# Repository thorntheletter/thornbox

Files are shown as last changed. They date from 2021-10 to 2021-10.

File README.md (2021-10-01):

# thornbox
Custom stickless controller compatible (probably) with most Brooks boards

This is my first time doing PCB design, CAD, and 3D printing so it is probably a bit rough.

## Current Issues:
* The DIP Switch description for tournament lockout is reversed.
* There is not enough room in the top of the case for player LEDs.
* Snackbox Micro buttons end up awkwardly high.
* 3D Printed buttons can be fragile and break easily.
* DP/LS/RS switches do not work. (I believe this to be a problem on the PCB manufacturers end.)
* The screws needing to go from bottom to top through PCB are tricky to get in right.
* I did not have the filament to iterate the tolerances more than once after fixing underextrusion.
* The files to generate pcb graphics footprints are missing (I may also need the hotswap socket / USB-C port footprints)
* The USB-C port is a pain to solder by hand.

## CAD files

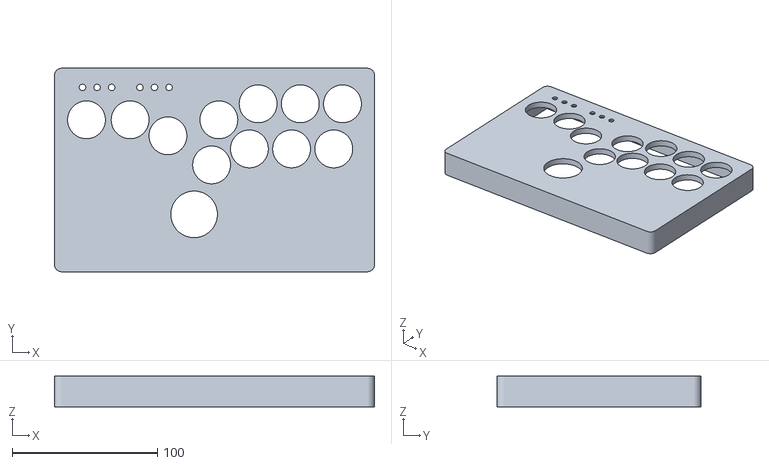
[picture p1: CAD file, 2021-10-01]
production/stl/top.stl
220.0 x 140.0 x 21.0

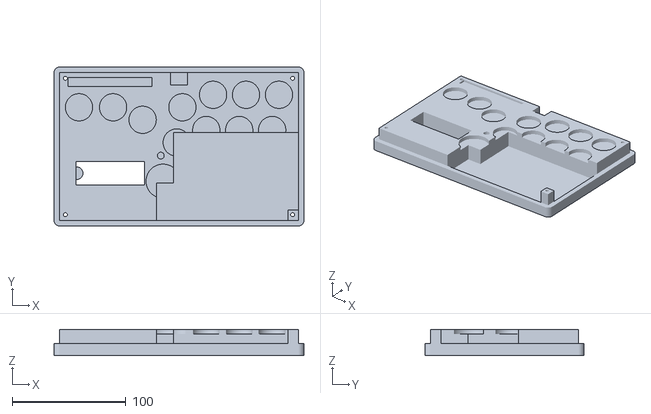
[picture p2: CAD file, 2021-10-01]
production/stl/bottom.stl
220.0 x 140.0 x 23.0

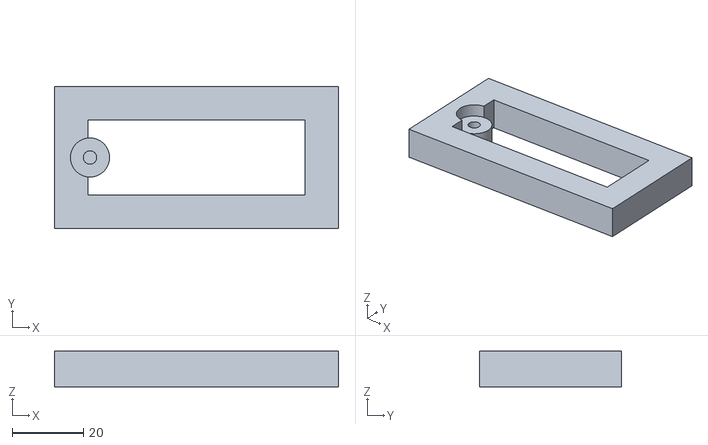
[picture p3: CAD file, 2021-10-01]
production/stl/diphatch.stl
80.0 x 40.0 x 10.0

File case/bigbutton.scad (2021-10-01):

$fa = .1;
$fs = .1;
module bigbutton(){
    union(){
        difference(){
            translate ([0,0,4]) minkowski(){
                        cylinder(2.5,r=15-4);
                        difference(){
                            sphere(r=4);
                            translate([0,0,50]) cube(100, center=true);
                       
                }
            }
            translate([0,0,1.5]) cylinder(9, r=15-1.5);
        }
        translate([0,2.85,1+2-.5]) cube([2.5,.9,5], center = true);
        translate([0,-2.85,1+2-.5]) cube([2.5,.9,5], center=true);
    }
}
bigbutton();

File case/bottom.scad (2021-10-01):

$fa = .1;
$fs = .1;
use <diphatch.scad>
layout = [[17,30.5],[47,30.5],[73,41.5],[91,95.5],
          [108,30.5],[135,19.5],[164,19.5],[193,19.5],
          [103,61.5],[129,50.5],[158,50.5],[187,50.5]];
upbutton = [91,95.5];
screws = [[89,57],[205,55],[117,5],[117,42],[205,42],[105,5]];
cornerscrews = [[5,125],[205,125],[5,5],[205,5]];
br = 10.6; //bottom rim
bh = 3; //how much space on bottom
eh = 20; //how much space to pcb(s)
hh = 100; //arbitrarily large for holes
sh = 2; //tht back side solder

module bottom(){
    union(){
   difference(){
        union(){
            difference(){        
                union(){
                    difference(){
                        minkowski(){
                                cube([210,130,br-1]);
                                cylinder(1,r=5);
                            
                        }
                        cube([210,130,eh+bh]);

                    }
                    cube([210,130,eh+bh]);
                }
                for(i = layout){
                    translate([i[0],130-i[1],bh+eh-4]) cylinder(hh, r=12);
                }
                translate([upbutton[0],130-upbutton[1],bh+eh-4]) cylinder(hh, r=15);
//                translate([14.25-7,130-8.25-4,bh+eh-sh]) cube([74,8,hh]);
                translate([14.25-7,130-8.25-4,bh+eh-sh]) cube([74,8,hh]);
//                translate([97.5,130-11,bh+eh-8]) cube([15,20,hh]);
                translate([97.5,130-11,bh+eh-8]) cube([15,20,hh]);
                translate([100,0,bh]) cube([110,130-52.5,hh]);
                translate([85,0,bh]) cube([210-85,130-97.,hh]);
                translate([15-.5,31.5-.5,-hh/2]) cube([60,21,hh]);
        translate([5,31.5-10,-hh+10]) cube([80,40,hh]);
            }

            translate([205.5,4.5,(bh+eh)/2]) cube([9,9,bh+eh], center=true);
        }
        for(i=cornerscrews){
            translate([i[0],i[1],-hh/2]) cylinder(hh, r=3.5/2);
            translate([i[0],i[1],-1]) cylinder(5.5, r=3);
        }
        for(i=screws){
            translate([i[0],i[1],eh+bh-3]) cylinder(3.5, r=3);
        }
    }
        translate([(15-10),40+(31.5-10),10]) rotate([180,0,0]) diphatch();
        
    }
}
bottom();

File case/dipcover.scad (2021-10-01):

$fa = .1;
$fs = .1;
difference(){
    union(){
        translate([0,-.25,0]) cube([60,20.5,4]);
        translate([59,17.5-15,0]) cube([5,5,1]);
        translate([59,17.5-5,0]) cube([5,5,1]);
        translate([0,10,0]) cylinder(h=4, r=5);
    }
    translate([0,10,-1]) cylinder(h=6, r=3.5/2);
    translate([0,10,2]) cylinder(h=6, r=3);
}

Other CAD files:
case/diphatch.scad
case/full.scad
case/smallbutton.scad
case/top.scad

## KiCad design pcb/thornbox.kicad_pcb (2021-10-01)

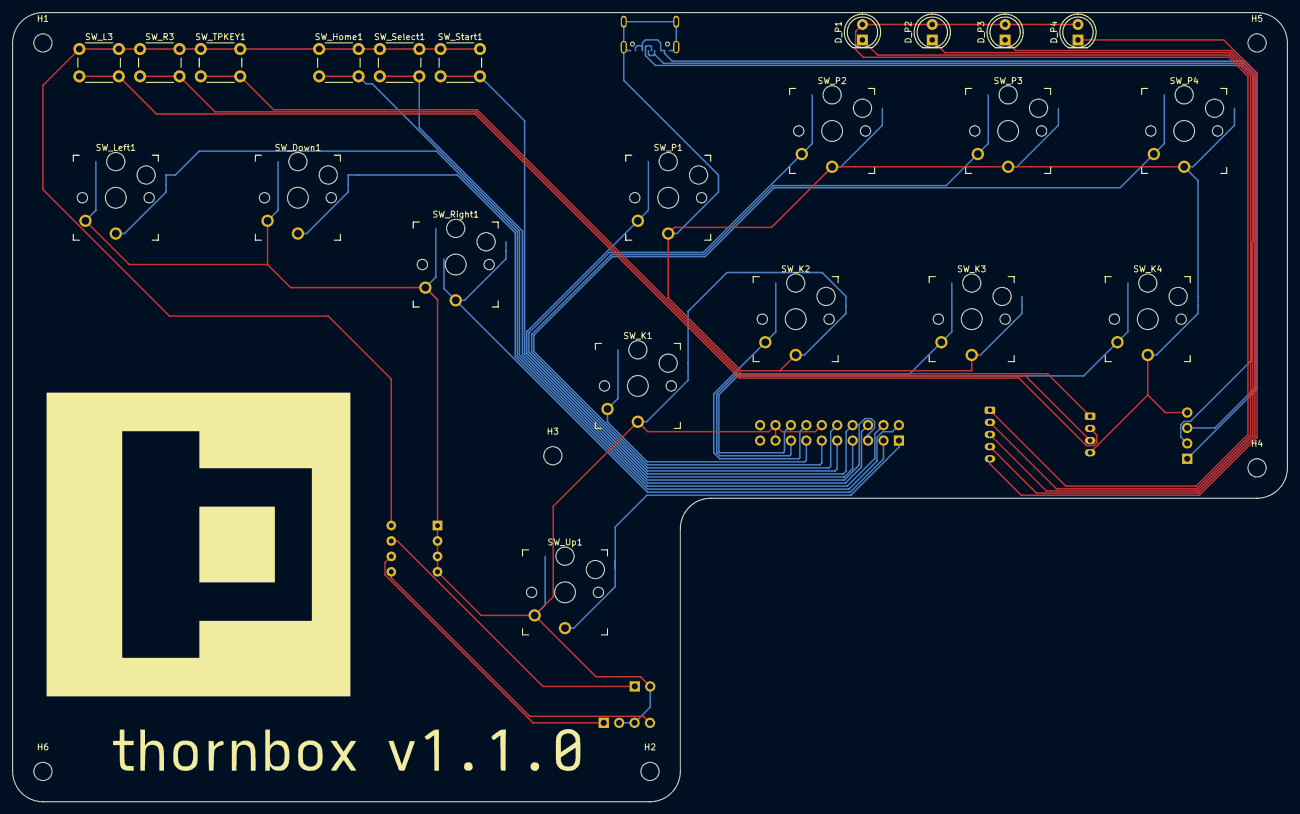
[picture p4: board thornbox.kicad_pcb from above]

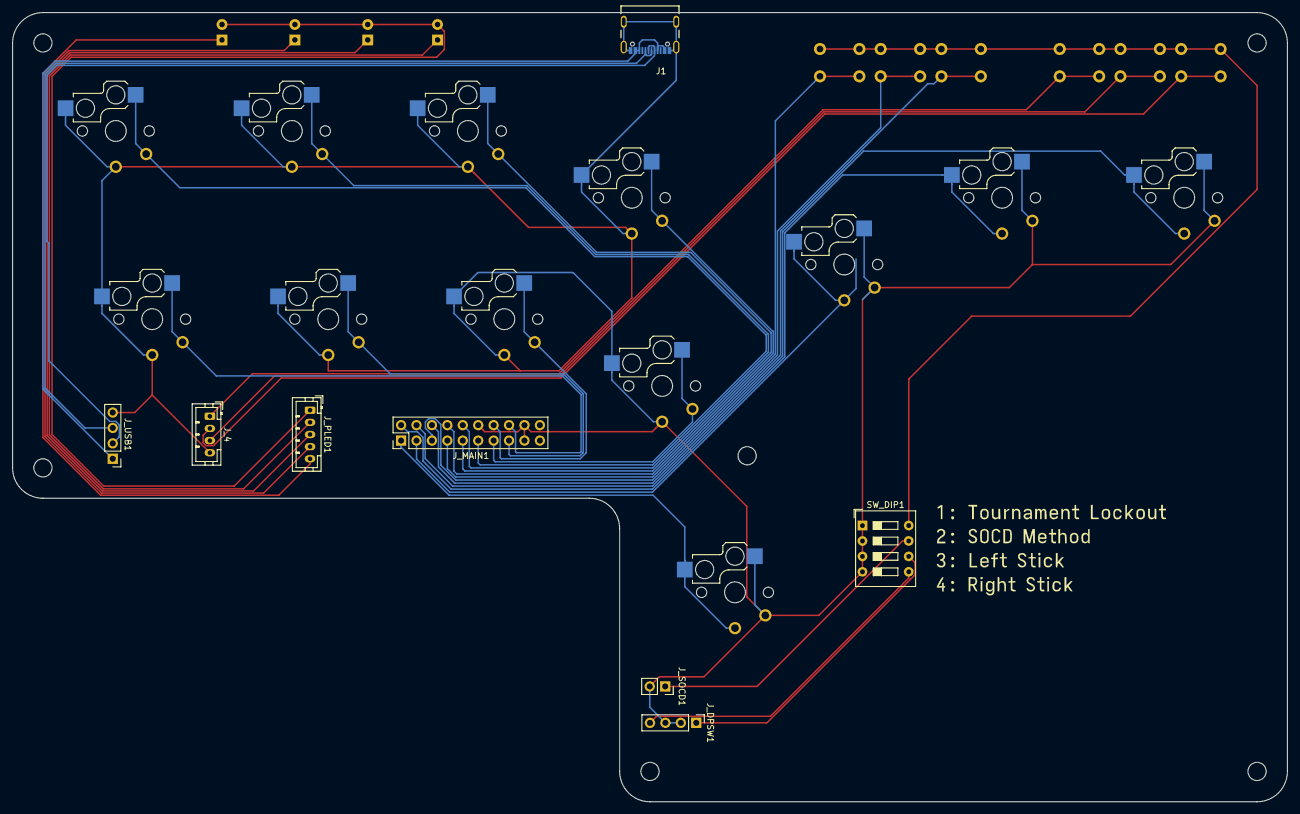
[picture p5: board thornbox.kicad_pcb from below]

Board: 2 copper layers, 210.0 x 130.0 mm, 39 parts (9 on the bottom side), 31 nets.

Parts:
DIPtext1: MountingHole; diplabel
D_P1, D_P2, D_P3, D_P4: LED; LED_D5.0mm
H1, H2, H3, H4, H5, H6: MountingHole; MountingHole_3mm
J1: USB4105-GF-A; GCT_USB4105-GF-A
J_4: Conn_01x04_Male; JST_PH_B4B-PH-K_1x04_P2.00mm_Vertical
J_DPSW1: Conn_01x04; PinHeader_1x04_P2.54mm_Vertical
J_MAIN1: Conn_02x20_Odd_Even; PinHeader_2x10_P2.54mm_Vertical
J_PLED1: Conn_01x05; JST_PH_B5B-PH-K_1x05_P2.00mm_Vertical
J_SOCD1: Conn_01x02; PinSocket_1x02_P2.54mm_Vertical
J_USB1: Conn_01x04_Male; PinHeader_1x04_P2.54mm_Vertical
Logo1: MountingHole; thethorn5
SW_DIP1: SW_DIP_x04; SW_DIP_SPSTx04_Slide_9.78x12.34mm_W7.62mm_P2.54mm
SW_Down1: SW_Push; Kailh_socket_PG1350_optional
SW_Home1: SW_Push; SW_PUSH_6mm
SW_K1, SW_K2, SW_K3, SW_K4: SW_Push; Kailh_socket_PG1350_optional
SW_L3: SW_Push; SW_PUSH_6mm
SW_Left1: SW_Push; Kailh_socket_PG1350_optional
SW_P1, SW_P2, SW_P3, SW_P4: SW_Push; Kailh_socket_PG1350_optional
SW_R3: SW_Push; SW_PUSH_6mm
SW_Right1: SW_Push; Kailh_socket_PG1350_optional
SW_Select1: SW_Push; SW_PUSH_6mm
SW_Start1: SW_Push; SW_PUSH_6mm
SW_TPKEY1: SW_Push; SW_PUSH_6mm
SW_Up1: SW_Push; Kailh_socket_PG1350_optional
version1: MountingHole; version

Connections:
Earth: J1.A1_B12, J1.B1_A12, J1.S1, J1.S2, J1.S3, J1.S4, J_4.4, J_DPSW1.2, J_DPSW1.3, J_MAIN1.12, J_MAIN1.17, J_MAIN1.18, J_SOCD1.2, J_USB1.4, SW_DIP1.1, SW_DIP1.2, SW_DIP1.3, SW_DIP1.4, SW_Down1.1, SW_K1.2, SW_K2.2, SW_K3.2, SW_K4.2, SW_Left1.1, SW_P1.2, SW_P2.2, SW_P3.2, SW_P4.2, SW_Right1.1, SW_Up1.1
unnamed: D_P1.1, J_PLED1.2
unnamed: D_P1.2, D_P2.2, D_P3.2, D_P4.2, J_PLED1.1
unnamed: D_P2.1, J_PLED1.3
unnamed: D_P3.1, J_PLED1.4
unnamed: D_P4.1, J_PLED1.5
unnamed: J1.A4_B9, J1.A5, J1.B4_A9, J1.B5, J_USB1.1
unnamed: J1.A6, J1.B6, J_USB1.3
unnamed: J1.A7, J1.B7, J_USB1.2
unnamed: J_4.1, SW_TPKEY1.2
unnamed: J_4.2, SW_L3.2
unnamed: J_4.3, SW_R3.2
unnamed: J_DPSW1.1, SW_DIP1.6
unnamed: J_DPSW1.4, SW_DIP1.5
unnamed: J_MAIN1.1, SW_Up1.2
unnamed: J_MAIN1.2, SW_Down1.2
unnamed: J_MAIN1.3, SW_Right1.2
unnamed: J_MAIN1.4, SW_Left1.2
unnamed: J_MAIN1.5, SW_Select1.2
unnamed: J_MAIN1.6, SW_Home1.2
unnamed: J_MAIN1.7, SW_Start1.2
unnamed: J_MAIN1.8, SW_P1.1
unnamed: J_MAIN1.9, SW_P2.1
unnamed: J_MAIN1.10, SW_P3.1
unnamed: J_MAIN1.11, SW_P4.1
unnamed: J_MAIN1.13, SW_K1.1
unnamed: J_MAIN1.14, SW_K2.1
unnamed: J_MAIN1.15, SW_K3.1
unnamed: J_MAIN1.16, SW_K4.1
unnamed: J_SOCD1.1, SW_DIP1.7
unnamed: SW_DIP1.8, SW_Home1.1, SW_L3.1, SW_R3.1, SW_Select1.1, SW_Start1.1, SW_TPKEY1.1

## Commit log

2021-10-01 initial commit: thornbox 1.1.0 (missing some files)
    [bigbutton.scad, bottom.scad, bottom.stl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]
2021-10-01 added gerbers
    [thornbox-B_Cu.gbr, thornbox-B_Mask.gbr, thornbox-B_SilkS.gbr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]
2021-10-01 added more current issues in readme and gitignore
